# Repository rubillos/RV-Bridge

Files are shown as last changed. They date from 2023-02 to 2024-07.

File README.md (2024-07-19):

# RV-Bridge: HomeKit to RV-C Adapter

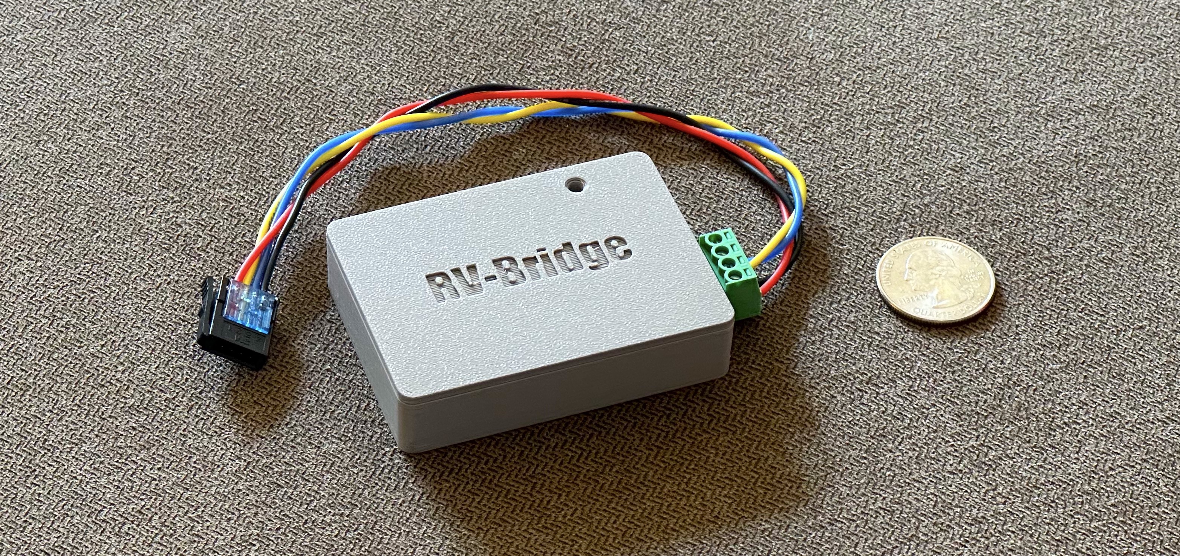
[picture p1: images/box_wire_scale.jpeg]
RV-Bridge


---

1. [Features](#features)
2. [Background](#background)
3. [Current Project State](#state)
4. [To-Do](#todo)
5. [Hardware](#hardware)
6. [Wiring](#wiring)
7. [Firmware Setup](#firmware)
8. [Finding Output Numbers](#outputs)
9. [Supported RVs](#rvs)
10. [3D Printing](#3dprint)
11. [Notes and Tips](#notes)
12. [Links](#links)

---
## Features

* Connects to the RV-C network in many modern RVs.
    * RV-C is a subset of CAN-Bus running at 250kbps.
* Uses an ESP32 with a CAN-Bus interface.
* Connects lights, fans, switches, and thermostats to HomeKit.
* Fits inside the RV wiring panel.
* Plugs into an unused CAN-Bus socket for power and data.
* STL files for a 3D printed case are included.

---
## Background

At the start of the pandemic we realized that international travel was going to be off the table for a significant duration. We decided it was time [to see more of the Western US](http://rickandrandy.com/map/index.html?RV) so we bought a class-A motorhome which we call ***The Penguin Express***. We've put [almost 30k miles on it so far](http://rickandrandy.com/?rvlife).

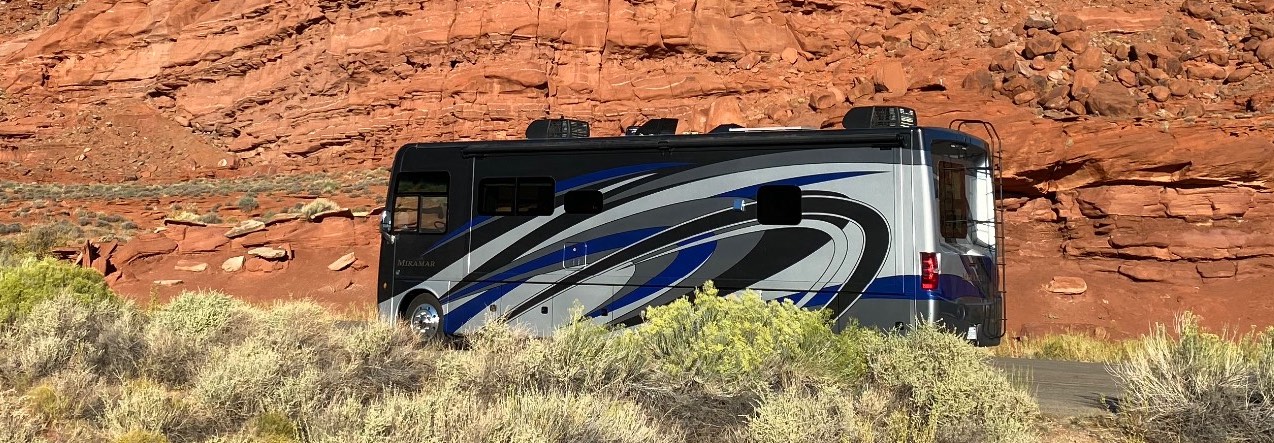
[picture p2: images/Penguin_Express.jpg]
Penguin Express


In addition to a bunch of 3D printed upgrades (we travel with a Prusa MK3S on board), I've done some arduino powered electronics work: a water valve for a reverse osmosis water filter with an LCD control panel, a GPS based clock for the bedroom that knows the exact timezone boundaries so it never needs to be set, and a GPS based altimeter and tire pressure monitor with a 7" color touchscreen for the dash.

The RV's lights, fans, and climate are all controlled through a [Firefly Integrations](https://fireflyint.com) [Vegatouch Spectrum](https://www.vegatouch.com) multiplex system. A 7" LCD panel is used to control everything, in addition to wireless keypads around the RV. There is also a bluetooth module that connects to an iOS app for controlling via an iPhone.

| | |
| --- | --- |
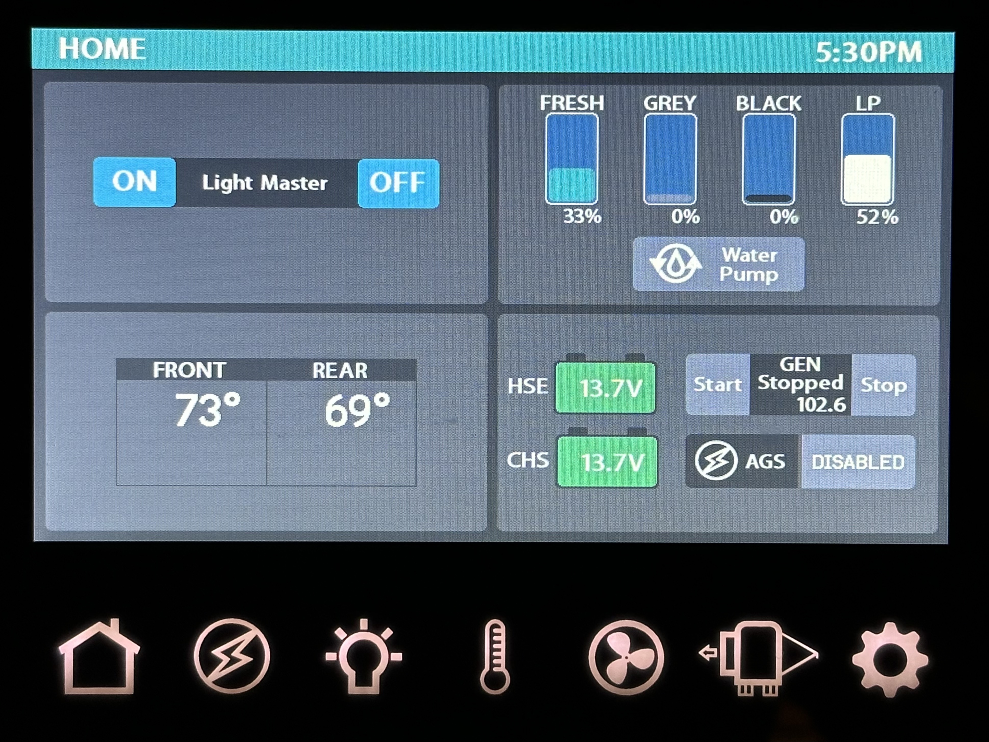
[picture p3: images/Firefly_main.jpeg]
Firefly Main
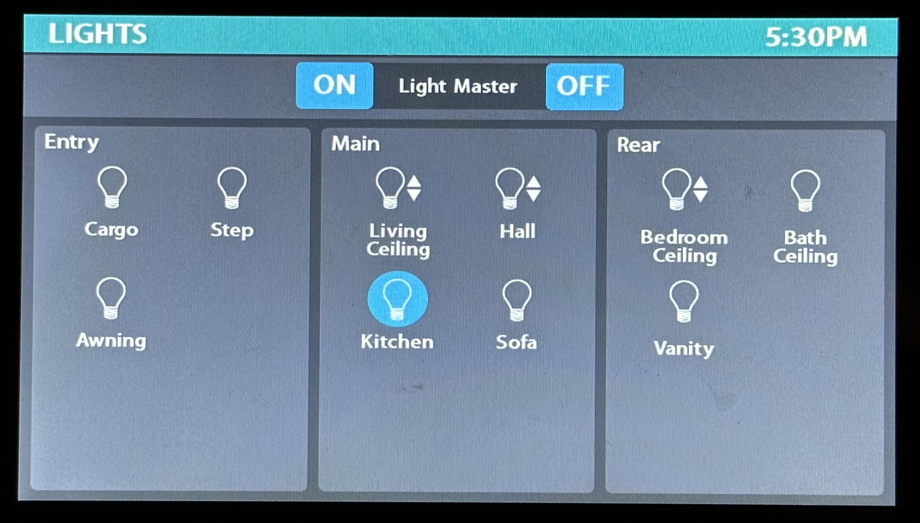
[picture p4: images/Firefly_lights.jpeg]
Firefly Lights
|  |  |
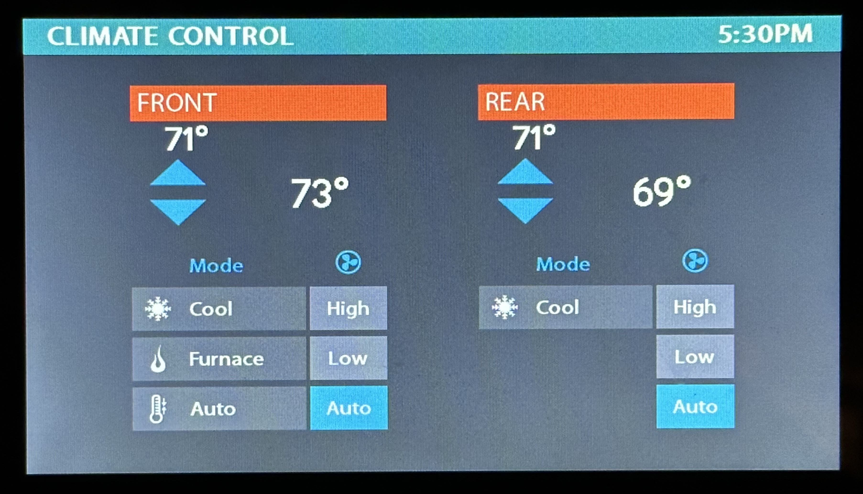
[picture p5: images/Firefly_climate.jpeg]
Firefly Climate
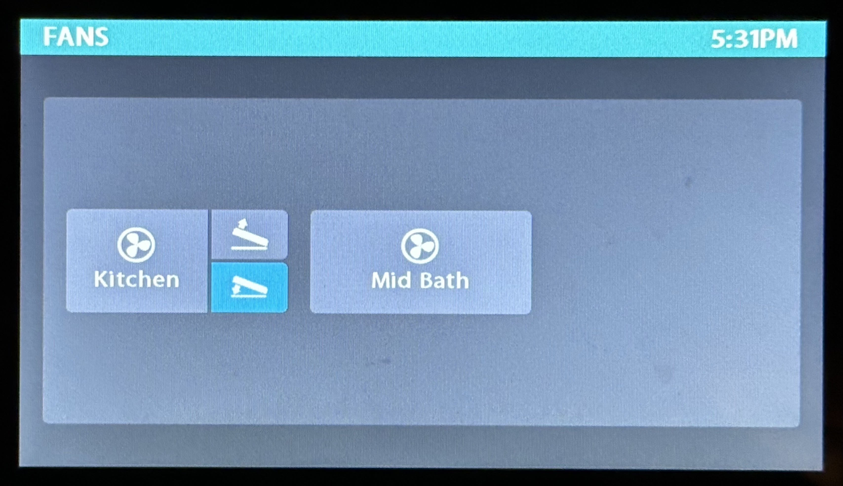
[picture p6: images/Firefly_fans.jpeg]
Firefly Fans
|  |  |

It's a great system and works really well for control of the RV devices, but the iOS app is a bit slow to load/connect and can only be used in proximity to the RV. Since we already have an Apple TV onboard driving our TVs which could double as a hub, I've always wondered if there was a way to control it all via HomeKit and the Home app.

Recently I came across some documentation for the bus protocol that's used by the Spectrum system, RV-C, a subset of CAN-Bus, as well as the open source project [CoachProxyOS](https://github.com/linuxkidd/coachproxy-os) that documents getting a Raspberry Pi set up to host a web page for controlling an RV's network using RV-C.

I also recently started playing with [HomeSpan](https://github.com/HomeSpan/HomeSpan), a library for implementing HomeKit accessories on an ESP32 microcontroller, for a HomeKit doorbell project.

RV-Bridge is the result of putting these pieces together.

---
## Current Project State

## v1.0.9 - In progress
* Added option to create two "Thermostats" which show the voltage of the chassis and house batteries as temperature * 10
* Added support for exterior awnings.

## v1.0.0
* Homespan pairing works, devices show up in the Home app.
* CAN-Bus packet receiving works.
* RV-C messages are routed correctly to the HomeKit tiles.
* The correct RV-C packets are being sent over the bus based on changes made in the Home app for lights, switches, and fans.
* The RV devices respond correctly.
* Lights, switches, and fans are complete.
* Temperature readings from thermostats are reflected in the Home app.
* Thermostat control is complete.

---
## To-Do

* Some RVs have AC units that can work as a heat pump; only the AC portion of these units is currently handled. (Ours only has a furnace so I don't currently have a way to implement this.)

---
## Hardware

Uses an ESP32 with a CAN-Bus interface, either as separate components, or more easily, this board I found from [skpang.co.uk](https://www.skpang.co.uk):

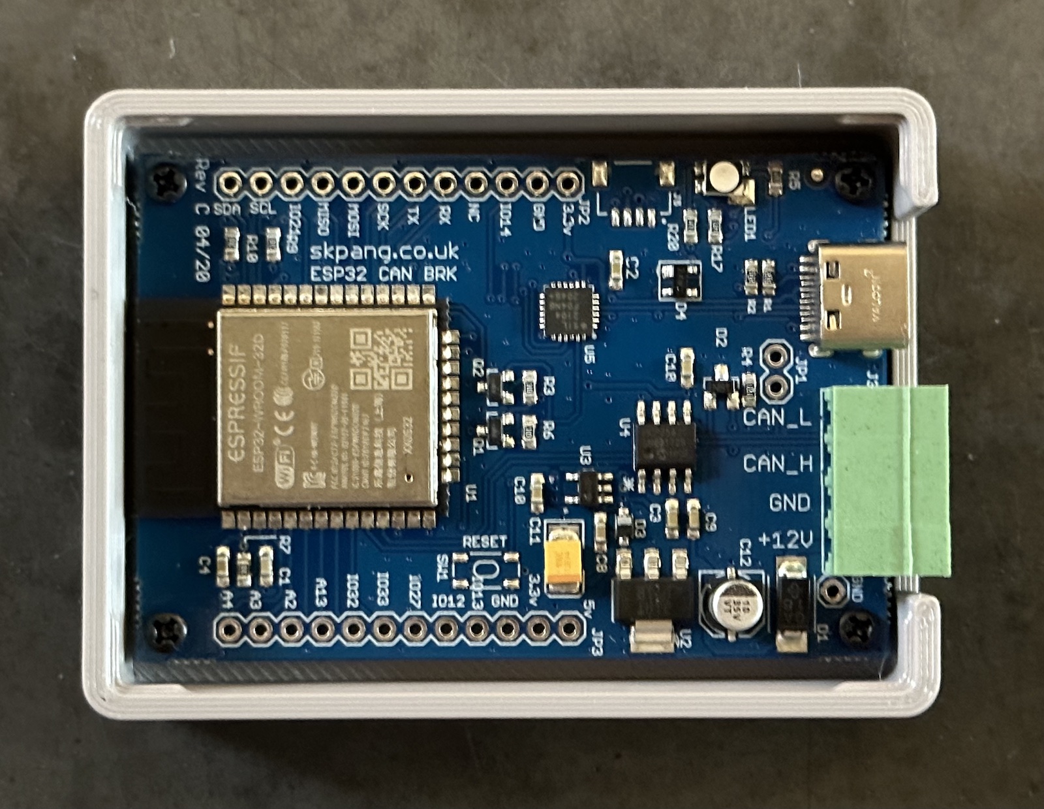
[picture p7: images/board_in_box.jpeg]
ESP32 Module


In the U.S. it's available on the CopperHillTech Website:<br>
[ESP32 with WiFi, Bluetooth Classic, BLE, CAN Bus Module](https://copperhilltech.com/esp32-wifi-bluetooth-classic-ble-can-bus-module/)

This board has everything needed, including a regulator for powering the device off of the 12V provided by the RV-C connector.

---
## Wiring

The connector used by the Firefly system is a ***3M 37104-A165-00E MB*** which can be sourced from [Digikey](https://www.digikey.com/en/products/detail/3m/37104-A165-00E%2520MB/1855697)

Insert four 24AWG wires into the Can-Bus connector (I used silicone covered wire as they are much more flexible) and compress to make the connections. Twist the data and power pairs together and screw them into the terminal block on the CAN-Bus interface on the ESP32.

The CAN-Bus connector plugs into one of the available sockets inside the system wiring panel.

|  |  |
| :---: | :---: |
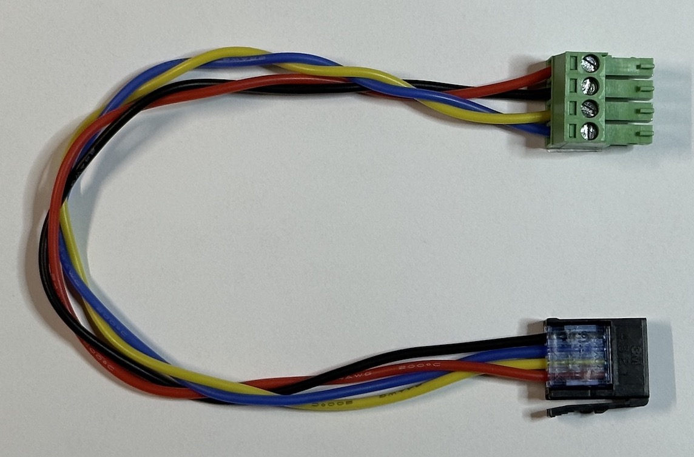
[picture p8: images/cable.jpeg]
Cable Wiring
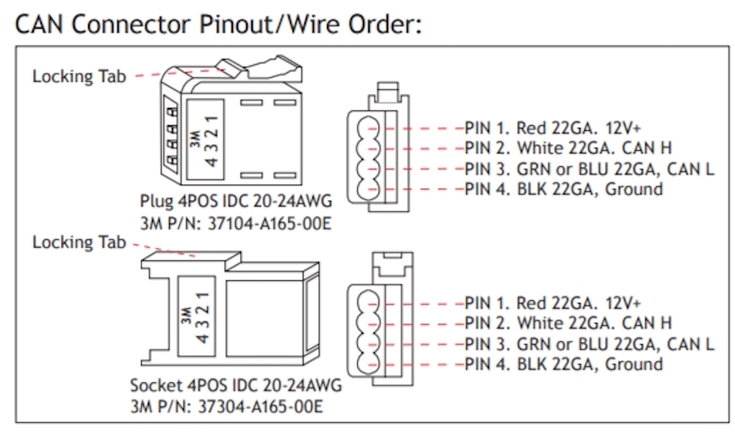
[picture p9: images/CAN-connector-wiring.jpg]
Can-Bus Connector Wiring
| <br> | |
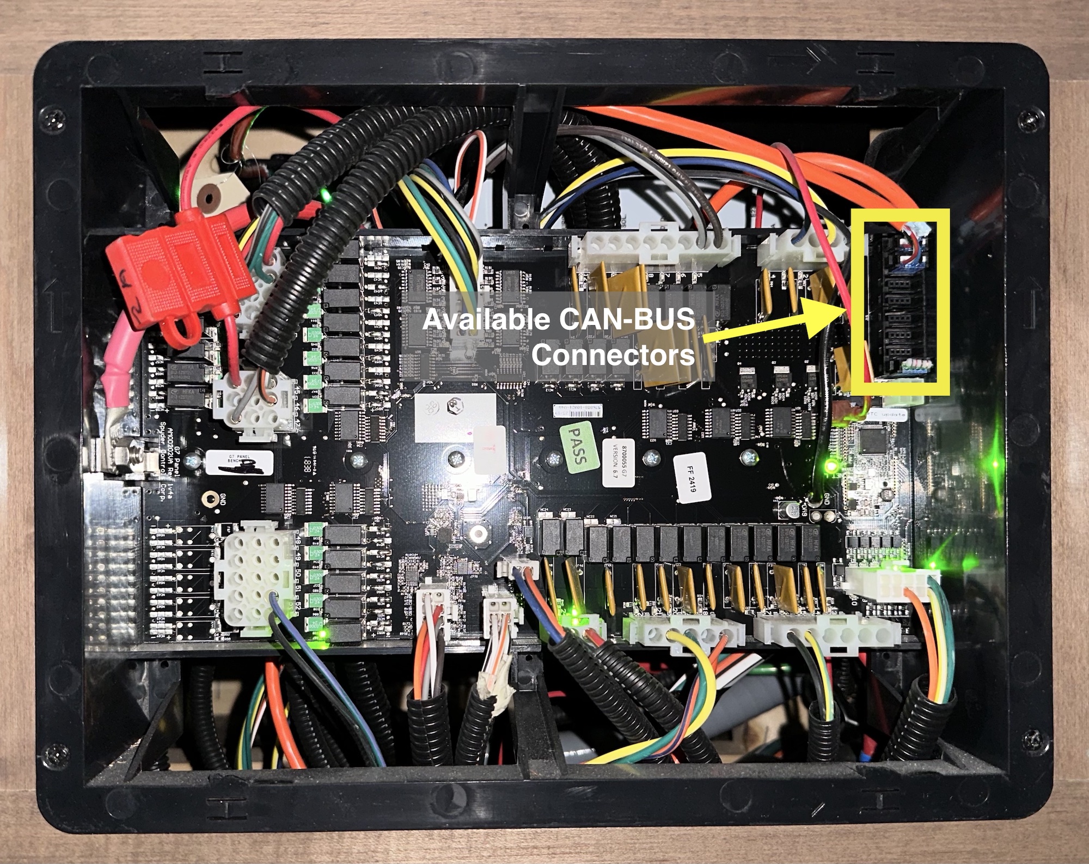
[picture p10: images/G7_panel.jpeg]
G7 Panel
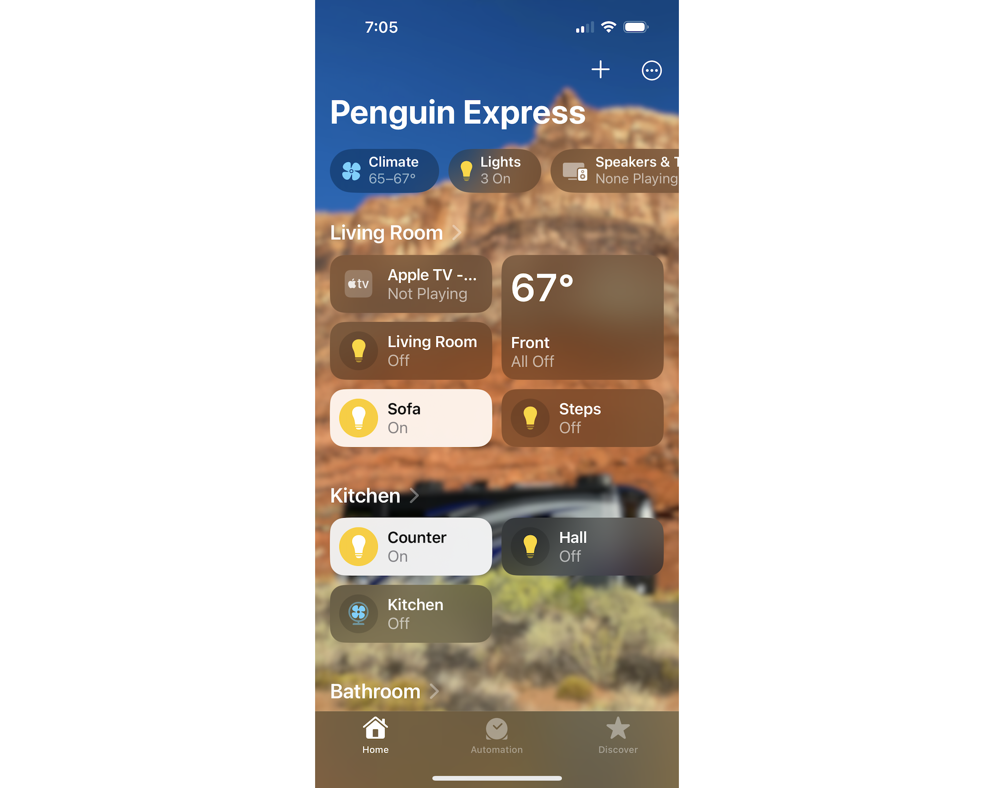
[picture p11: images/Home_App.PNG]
Home App
|  |  |

---
## Firmware Setup

- The project is set up for compilation with PlatformIO.
    * I use it via Microsoft's Visual Studio Code.
- Pretty sure you could also use the Arduino IDE. You'd need to install the following libraries:
    * elapsedMillis
    * miwagner/ESP32CAN
    * homespan/HomeSpan
- `config.h`
    * Duplicate `config-sample.h` to `config.h`. (Do not check this file into git, it will have your wifi passowrd in it)
    * Enter Wifi SSID and password for your RV network.
    * Include a definition file for your RV devices (see `Miramar_2020_3202.h` for an example).
        * Each switch has:
            * Output number.
            * Type: Lamp, DimmableLamp, or Switch.
            * Name.
        * Each fan has:
            * Output number for fan power.
            * Output number for up - optional, -1 if not used.
            * Output number for down - optional, -1 if not used.
            * Name.
        * Each thermostat has:
            * ID number, typically 0 based.
            * Output number for the A/C compressor.
            * Output number for low fan.
            * Output number for high fan.
            * Output number for furnace - optional, -1 if not present.
            * Name.
        * Each awning has:
            * Output number for extend.
            * Output number for retract.
            * Time (in ms) that the awning takes to get to the "unroll" portion.
            * Time (in ms) that the awning takes to "unroll" at the end. Set to 0 if not applicable.
            * Time (in ms) that the awning takes to get from the "roll" portion to fully retracted.
            * Time (in ms) that the awning takes to "roll" at the beginning. Set to 0 if not applicable.
            * Name.
        * See [Finding Output Numbers](#outputs) below for details on output numbers.
    * Uncomment `#define CREATE_BATTERIES` to create "Thermostats" for the house and chassis batteries.
        * The "thermostat" will show the current battery voltage times 10 as temperature.
            * Homekit does not currently have a way to display voltages, so this is my hack to be able to see this very useful information.
        * You will likely want to turn off "Include in Home Summaries" in the Status setting for these "thermostats".
        * When in screen "rearrange" mode you can tap on a thermostat and choose to show it in a smaller sized tile.
- Flashing
    * If you are using an ESP32 with a USB-C connector and flashing from a Mac, you may need to connect it via a USB hub due to some timing weirdness around resetting the ESP32 into boot mode. I use a USB-C to 4 port USB-A hub with a USB-A to USB-C cable.
- Startup
    * Connect to the ESP32 via the Serial Monitor.
    * You should see a bunch of startup logging.
    * Then a message about being connected to Wifi and not being paired.
    * HomeSpan provides a command line interface that you can access through the Serial Monitor. Type '?' to see the available comands.
- Pairing
    * Be on the same wifi network and in close proximity to the ESP32.
    * In the Home app choose "Add Accessory".
    * Point the camera at this image:
    <br><br>
    Pairing Code
    <br><br>
    * Tap on `RV-Bridge`.
    * Accept that this is an "unsupported" device.
    * Add the bridge and all of your accessories, choosing appropriate rooms and names for them.
    * Done!
- The status LED will flash based on what the bridge is doing:
    * 🟢 Green every 2 seconds as a heartbeat indicator.
    * 🔴 Red when CAN-Bus packets are sent.
    * 🔵 Blue when HomeKit messages are received.

---
## Finding Output Numbers

The whole multiplex system connects back to a panel with outputs for all of the lights and fans. Each of these outputs has a unique number which may be printed on the panel's cover, and should also be found on a Network Diagnostic screen on the main LCD control screen.

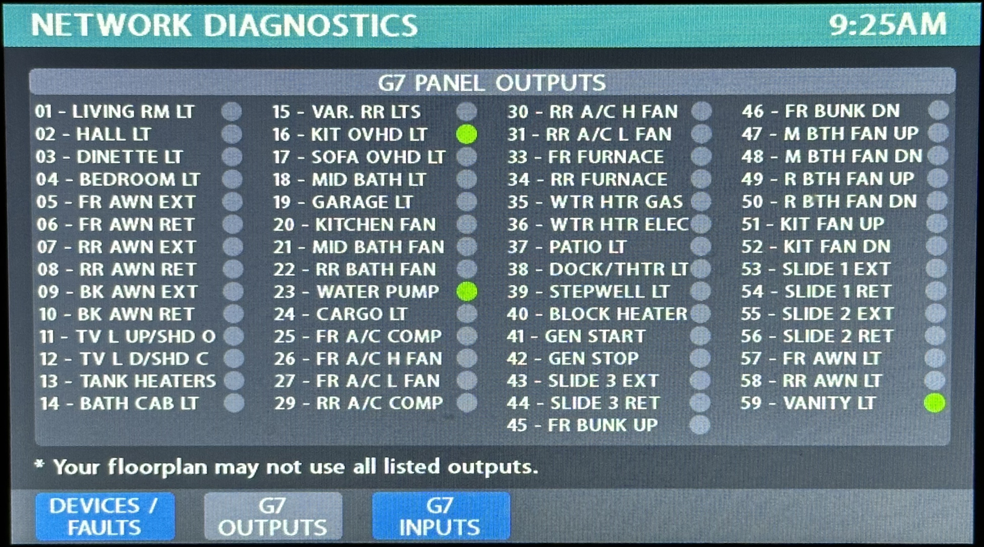
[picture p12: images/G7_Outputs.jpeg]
G7 Outputs


*** ***USE EXTREME CAUTION WHEN ENTERING OUTPUT NUMBERS. THERE ARE OUTPUTS FOR THE RV SLIDES AND THINGS LIKE MOVEABLE BUNKS. YOU DO NOT WANT TO MISTAKENLY PICK ONE OF THOSE OUTPUTS FOR A LIGHT OR FAN!*** ***

---
## Supported RV's

Currently the project includes definition files for these RVs in the `RV` folder:

[Miramar_2020_3202.h](/src/RV/Miramar_2020_3202.h) - 2020 Thor Miramar 32.2<br>
[Aria_2019_3901.h](/src/RV/Aria_2019_3901.h) - 2019 Thor Aria 39.1<br>
[Tiffin_2019_34PA.h](/src/RV/Tiffin_2019_34PA.h) - 2019 Tiffin Open Road 34PA<br>
[Jayco_2023_Terrain.h](/src/RV/Jayco_2023_Terrain.h) - 2023 Jayco Terrain 19Y

(Additional definition files are welcome!)

---
## 3D Printing

- A case will keep the microcontroller isolated from any exposed contacts inside the wiring panel.
- STL Files are in the `3D` folder:
    * [RV-Bridge_Box_Bottom.stl](/3D/RV-Bridge_Box_Bottom.stl)
    * [RV-Bridge_Box_Top.stl](/3D/RV-Bridge_Box_Top.stl)
- Slicer
    * I used Prusa Slicer 2.5.0
- Build Plate
    * A textured build plate give a nice surface finish for the top and bottom of the box.
- Filament
    * PETG - handles heat better than PLA and sticks to a textured build plate much better than PLA.
- Settings to adjust:
    * `Layer Height`: 0.3mm (faster printing)
    * `Extrusion Width`: 0.55mm (eliminates tiny infill strips in the walls).
    * `Perimeter Transitioning Threshold Angle`: 20 (keeps the lettering connected).
    * `Bridging Angle`: 180º (bridging in the layer above the lettering should be parallel to the baseline of the text.)

---
## Notes and Tips

- If the bridge seems to become unresponsive at some point, verify that the controlling device is on the RV's Wifi and not some other weak Wifi.
- If the bridge doesn't seem available for pairing, it may already think it's paired. Try using the H command via the cli in the serial monitor, then reflash the ESP32 and try again.
- If pairing fails, it seems that sometimes HomeKit gets fussy about a device changing it's properties too much and refuses to pair. You can change the MAC address of the wifi interface on the ESP32 by defining `OVERRIDE_MAC_ADDRESS` in `config.h` and re-flashing. Anecdotal evidence suggests that this can help.

---
## Links:

- [Apple's HomeKit Accessory Protocol Specification Release R2 (HAP-R2)](https://developer.apple.com/homekit/specification/)
    * For some reason this link appears to be broken on the Apple side at the moment... with _just a tiny bit_ of hunting on the internet you can find it 😉
- [RV-C Organization](http://www.rv-c.com)
- [RV-C Spec 2022-12-01](http://www.rv-c.com/sites/rv-c.com/files/RV-C%20Protocol%20FullLayer-12-01-22.pdf)
- [SK Pang Electronics](https://www.skpang.co.uk)
- [Schematic for the ESP32 CAN-Bus Board above](https://cdn.shopify.com/s/files/1/0563/2029/5107/files/ESP32_CAN_rev_B.pdf?v=1620032162)

---

Copyright © 2023-2024 [Randy Ubillos](http://rickandrandy.com)

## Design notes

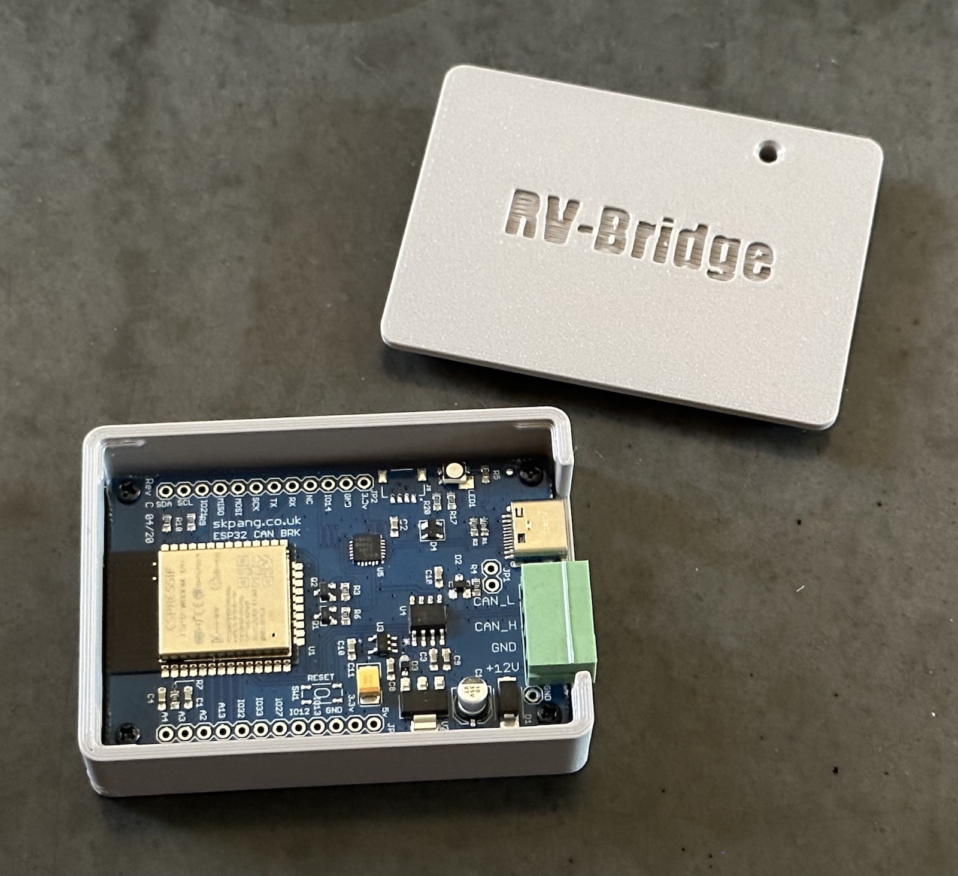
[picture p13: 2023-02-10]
images/open_box.jpeg

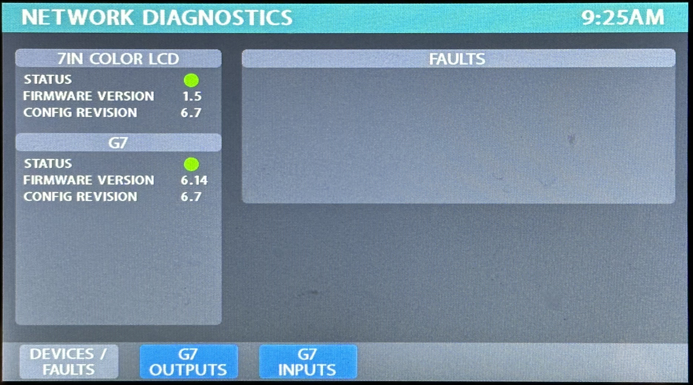
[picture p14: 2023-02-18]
images/G7_Devices.jpeg

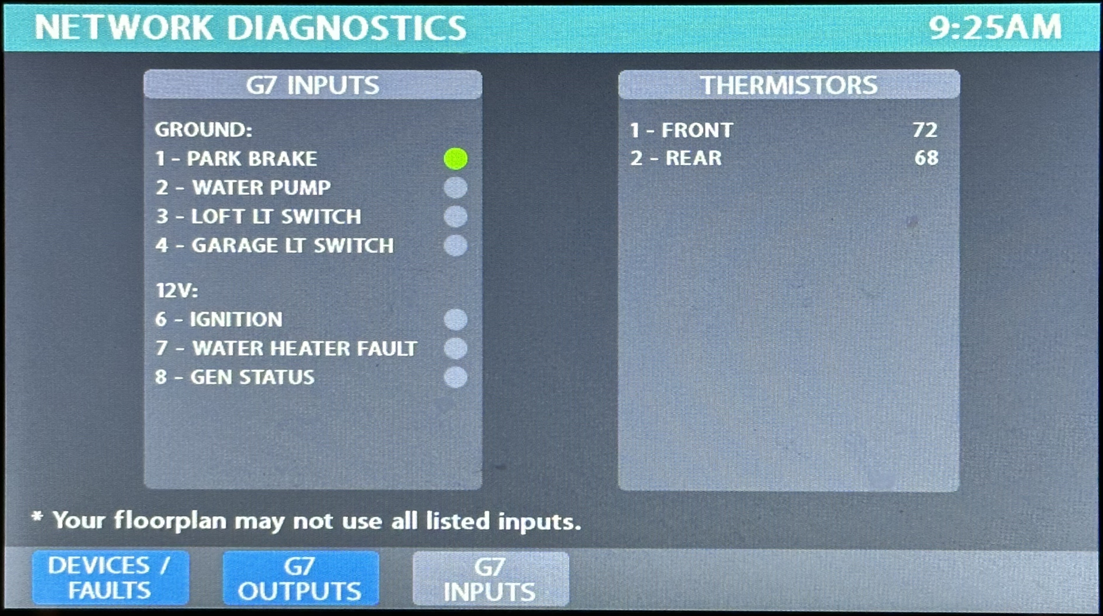
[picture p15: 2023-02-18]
images/G7_Inputs.jpeg

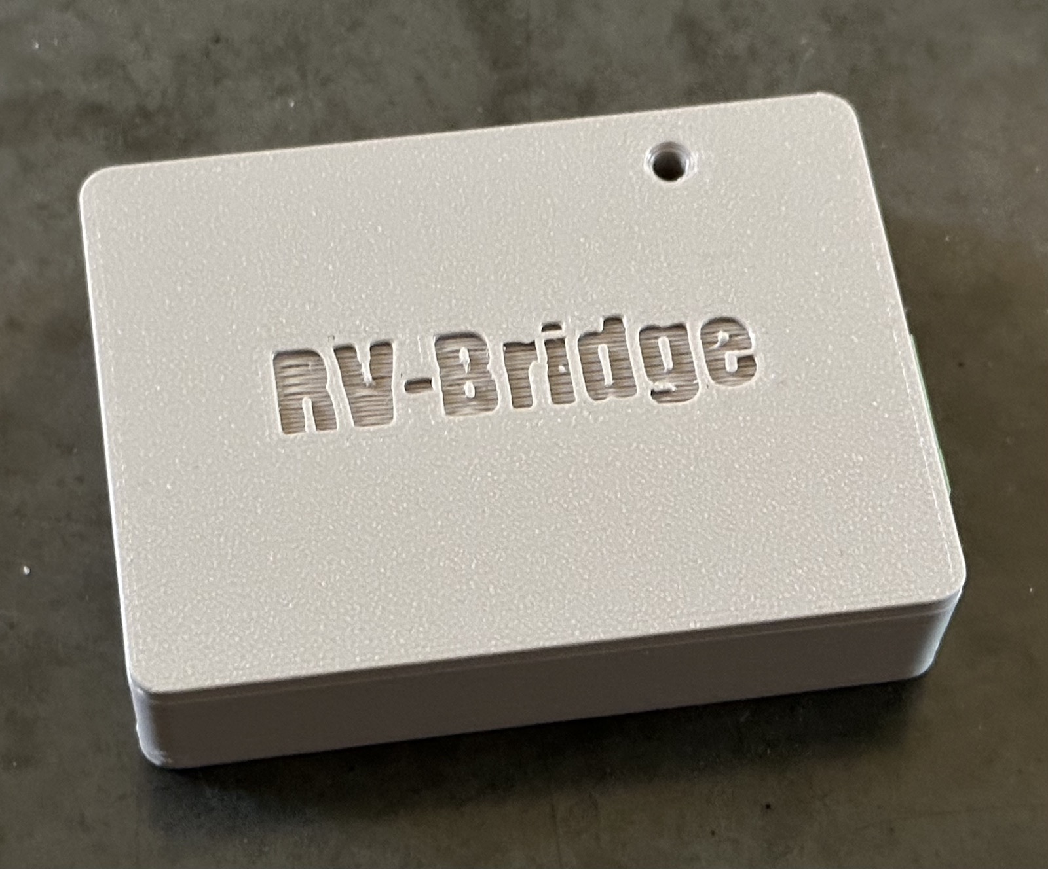
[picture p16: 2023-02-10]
images/box.jpeg

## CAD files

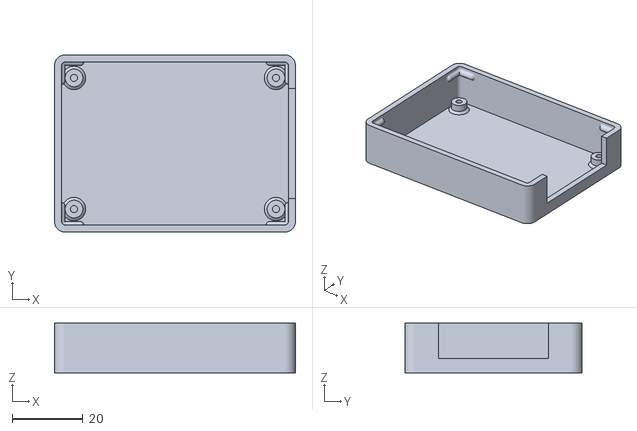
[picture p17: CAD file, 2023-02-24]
3D/RV-Bridge_Box_Bottom.stl
68.0 x 50.0 x 14.0

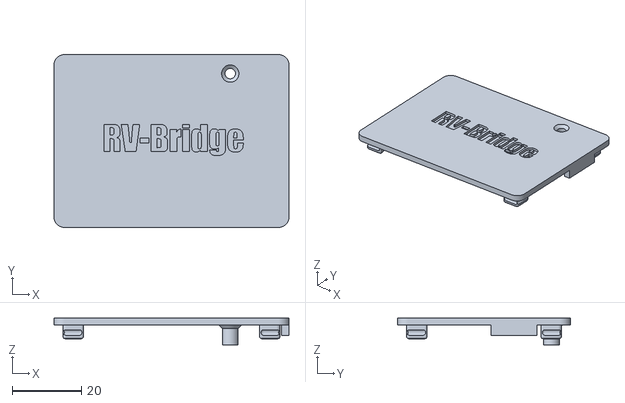
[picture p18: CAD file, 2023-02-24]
3D/RV-Bridge_Box_Top.stl
68.0 x 50.0 x 7.80

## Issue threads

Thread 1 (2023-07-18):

Can I use a Rpi and CAN board instead of the micro controller?

oilcan-productions, 2023-07-18:
I have a coachproxy setup from a previous project that I abandoned a year ago. Could the software be adapted to run on an RPi 4 with a CAN board attached>

rubillos, 2023-07-19:
That wouldn’t be easy… this project is codes using the HomeSpan library which is designed for the ESP32. I think you’d have an easier time using the coachproxy definition files for your Motorhome to define a setup file for this project.

oilcan-productions, 2023-07-27:
Thanks I got one of the ESP32 boards now.

Closed 2023-07-27.

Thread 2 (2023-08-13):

Feature Request: Awning Control and Heat Pump

kwe1009, 2023-08-13:
I have a 2019 Tiffin and your code works great with it but I would like to be able to control my awning and heat pump.  I'm not much of a programmer and all of my attempts to make this happen have been unsuccessful at best.

rubillos, 2023-08-14:
I'm planning to add support for awnings in a couple of months (we store our RV about an hour away so I really only get to work on this software when I'm traveling in it). Awnings are a bit tricky because the software has to estimate the position of the awning based on the amount of time since the button presses. I have some ideas on how to implement it and will be working on it on our next trip in October.

Did you create a configuration file for you Tiffin? If so I'd love to incorporate it into this project. Thanks!

kwe1009, 2023-08-14:
Thanks.  Attached is my Tiffin file which I am still working on.  I had a
CoachProxy but the CAN bus board just died so I'm trying your solution
which I really like better.  I don't have Apple products but I'm using the
Home KIt bridge with Home Assistant and it is working great.

Michael W.

On Mon, Aug 14, 2023 at 10:47 AM Randy Ubillos ***@***.***>
wrote:

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

rubillos, 2023-08-14:
I don't think GitHub has a way to add attachments to issues. (If you replied to the GitHub email any attachment would be ignored). Could you send the file to my email at randy@mac.com? Thanks!

rubillos, 2023-08-16:
Great, got the file, thanks!

Closed 2023-08-16.

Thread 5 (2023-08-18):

Enhancement: Support heat pump heating

rubillos, 2023-08-18:
Placeholder for planned future feature.

pbryan7, 2024-01-29:
I just got RV-Bridge working in my 2022 Entegra Vision XL 36A (I'll work on uploading a config file).   My unit has 2 A/C's, 2 Gas Furnaces, and the Heat Pump option on the Front A/C.  Through firefly it has 2 thermostat zones (front & rear).   The rear has A/C and Gas Furnace.   The Front has A/C, Heat Pump, & Gas Furnace.  Pretty close to max complexity on the HVAC.    I'm happy to help in any way I can to get the HeatPump working through RV-Bridge.

rubillos, 2024-01-29:
That's great! If you send me your config file I'll add it to the project.

As for the heat pump, it's hard for me to code that as we don't have on in our RV. Could you take pictures of the "G7 Panel Outputs" screen on your FireFly system in 4 states?

- Off
- A/C cooling
- Heatpump heating
- Furnace running

That would let me see what your system needs for the various modes.

Thanks,
Randy

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

pbryan7, 2024-01-30:
So I actually have a G12 not a G7, but all the output numbering seems to work the same.

Here's a pic of the overall outputs, next time I'm out at the RV I'll try to get pics of the different modes working, but it seems the heat pump is just another numbered output like the A/C Compressor or Furnace Enable  (See output #10)...

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

rubillos, 2024-01-30:
Good to know, that’s kind of what I was expecting.HomeKit doesn’t have any concept of a heating system with 2 different heaters. It could either be done with a separate switch that selects the furnace or heat pump, or a whole other “thermostat” for the furnace where the two thermostats turn each other off. Thoughts?RandyOn Jan 29, 2024, at 5:43 PM, pbryan7 ***@***.***> wrote:
So I actually have a G12 not a G7, but all the output numbering seems to work the same.
Here's a pic of the overall outputs, next time I'm out at the RV I'll try to get pics of the different modes working, but it seems the heat pump is just another numbered output like the A/C Compressor or Furnace Enable  (See output #10)...
20240126_194321.jpg (view on web)

—Reply to this email directly, view it on GitHub, or unsubscribe.You are receiving this because you were assigned.Message ID: ***@***.***>

pbryan7, 2024-01-30:
Ultimately I'm hoping to create some automatons around the thermostat, possibly connecting the RV-bridge to a Home Assistant instance...

Ideally, I'd be able to choose either Heat Pump, or Furnace, or both (I think it will work that way through the screen).  I don't have a strong preference on how that would be accessed...   Maybe it would make the most sense to have switches that would enable/disable the heating devices actuated by the main thermostat?

rubillos, 2024-01-30:
Hadn’t considered both at the same time… is that possible? I don’t see anything in the RV-C spec that would allow that. Would be great if you could confirm in the coach that that actually works.RandyOn Jan 29, 2024, at 7:04 PM, pbryan7 ***@***.***> wrote:
Ultimately I'm hoping to create some automatons around the thermostat, possibly connecting the RV-bridge to a Home Assistant instance...
Ideally, I'd be able to choose either Heat Pump, or Furnace, or both (I think it will work that way through the screen).  I don't have a strong preference on how that would be accessed...   Maybe it would make the most sense to have switches that would enable/disable the heating devices actuated by the main thermostat?

—Reply to this email directly, view it on GitHub, or unsubscribe.You are receiving this because you were assigned.Message ID: ***@***.***>

rubillos, 2024-01-30:
And just a note: you can create more automations with HomeKit than what the Home app allows. Something like the Eve app allows more complex automations to be created without needing Home Assistant.RandyOn Jan 29, 2024, at 7:04 PM, pbryan7 ***@***.***> wrote:
Ultimately I'm hoping to create some automatons around the thermostat, possibly connecting the RV-bridge to a Home Assistant instance...
Ideally, I'd be able to choose either Heat Pump, or Furnace, or both (I think it will work that way through the screen).  I don't have a strong preference on how that would be accessed...   Maybe it would make the most sense to have switches that would enable/disable the heating devices actuated by the main thermostat?

—Reply to this email directly, view it on GitHub, or unsubscribe.You are receiving this because you were assigned.Message ID: ***@***.***>

pbryan7, 2024-02-03:
OK, so I tested it today...   you can definitely have both the heat pump and furnace on at the same time.   Works both through the screen in the unit, see screenshots below, and through the phone app.

Heat Pump Only:
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

Heat Pump + Furnace:
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

rubillos, 2024-02-03:
Thanks, that's great info! I think I know how this is handled now. I'll get something coded up and we can see. (Note: I'm traveling for the next 2 months, so it will be a bit before I can get to this).

pbryan7, 2024-09-09:
> Thanks, that's great info! I think I know how this is handled now. I'll get something coded up and we can see. (Note: I'm traveling for the next 2 months, so it will be a bit before I can get to this).

Just checking in to see if there are any updates on this one...

pbryan7, 2025-05-15:
I was able to play with this a little this week...   After looking at the RV-C spec, and seeing that for a given thermostat instance the 'heat' mode is actually the heat pump (if available), and not the furnace, it gave me an idea that I could potentially make multiple thermostat entries in the config file.

The good news is that it seems to actually be working...    I'll have to play a bit more, but in a few tests today, I was able to choose to turn on & off the A/C, Heat Pump, & Furnace separately...

 In my case I have Front & Rear roof A/C (only the front has a Heat Pump), and I have front and rear propane furnaces.

I set up 4 thermostats like this:

const ThermostatDeviceRec thermostatList[] = {
    0, 9, 11, 12, 0, 10, "Front Roof",
    1, 13, 15, 16, -1, -1, "Rear Roof",
    0, 9, 11, 12, 2, 39, "Front Furnace",
    1, 13, 15, 16, 3, 2, "Rear Furnace"

Ideally there would be a way to define the furnace only thermostats, I wasn't sure what I should do with the A/C side of the furnace entries, so I just replicated the roof a/c instances & output numbers, but it seems to work fine.  You can see my output #'s in the photos above...   Notice I used the instance # of 0 for both the A/C & Heat items in the first thermostat, that is the key to accessing the heat pump.

Might be a little hacky, but so far seems to be working, at least in my unit (2022 Entegra Vision XL)...

shaferz, 2025-07-23:
Good stuff.  We are acquiring a new Brinkley that is coming with the firefly control system.  All 3 roof units have heat pumps, plus the propane furnace on top of that.  I've already got the ESP32 board, wiring connectors, etc.  Rig should be delivered in early October, so hoping by the end of October, I've got some time to really play around with this. 😎

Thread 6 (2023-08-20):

Add capability to configure Wi-Fi settings without rebuilding the code

oilcan-productions, 2023-08-20:
I have several Wi-Fi hotspots I use the adapter with. currently I modified a private build to scan for Wi-Fi and select the right access point  and password from a list rather than a single AP in the config file.

I think the functionality that if the configured wifi is not found the device comes up in AP mode and I can connect to a simple page to configure wifi there and write that to the NVRAM or the config file would be great.

oilcan-productions, 2023-08-20:
I am going to take a stab at this over the next 2 weeks or so and send a PR

rubillos, 2023-09-05:
Great! (I'd suggest just adding a #ifdef on said around setWifiCredentials so if said is not defined then you can just use the HomeSpan serial commands to set/change the wifi setup).

mkostersitz, 2023-09-26:
Thanks for the suggestion. I submitted https://github.com/rubillos/RV-Bridge/pull/8/ with the change

rubillos, 2023-09-28:
Added ability to not set wifi credentials by defining SKIP_WIFI_CREDENTIALS.

Closed 2023-09-28.

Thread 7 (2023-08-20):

When plugged into CAN bus and USB/Serial no output in Serial terminal

oilcan-productions, 2023-08-20:
Not sure what happened it used to work fine. Now when I plug it into the socket at the back of the Van and the laptop at the same time I am not getting Serial output.

oilcan-productions, 2023-08-20:
I plugged it in the wrong way round. Needs to be Serial first and CAN bus after :)

Closed 2023-08-20.

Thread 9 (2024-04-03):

Just received Cooperhill ESP32 Can

rlust, 2024-04-03:
Checking to see if you have any words of advice to give this a try. I have an 2022 Entergra Aspire and added my devices to the config file.

carpenike, 2024-08-13:
Following here too. 2021 Entegra Aspire.

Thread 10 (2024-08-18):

Suddenly stopped working

kwe1009, 2024-08-18:
I had to get a new ESP-CAN Bus and I can't get it to connect to homekit.  I can see the device on the network but when I scan the image nothing happens.  I'm also using Home Assistant and tried adding it using their homekit integration and no luck there either.  I can ping the device and it is on the same network as Home Assistant and the iPhone.  I have reflashed it countless times and even redownloaded 1.0.0 and started from scratch.

Also, the OVERRIDE_MAC_ADDRESS doesn't work

Any suggestions?  Thanks.

rubillos, 2024-08-18:
Have you tried rebooting your HomeKit hub? (I had an LED light I made using HomeSpan become unresponsive. I tried debugging it but took a break when nothing seemed to work. A couple of days later I noticed it was working again so it seemed like the issue may have been on the HomeKit side).

If you have a second iOS device that could be a HomeKit Hub you might try creating a second "Home", move an iOS device to it to be the hub for that "Home", then try adding the RV-Bridge to that home. I don't know what stale data there is that could cause a problem on the HomeKit side, but starting a whole new "Home" seems like it would start completely from scratch. Just a wild guess.

kwe1009, 2024-08-18:
Thanks for the quick response.  I tried all of that and no love.  I'll give
it a few more days to see if it works.

Michael W.

On Sun, Aug 18, 2024 at 11:05 AM Randy Ubillos ***@***.***>
wrote:

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

kwe1009, 2024-08-18:
Any ideas on why the change MAC address isn't working?  Thanks.

Michael W.

On Sun, Aug 18, 2024 at 11:05 AM Randy Ubillos ***@***.***>
wrote:

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

rubillos, 2024-08-18:
So the MAC address isn't actually changing? I thought you meant changing it wasn't helping...

Two thoughts. First, I found this when searching the web:
```
Attention: the bit 0 of the first byte of MAC address can not be 1. For example, the MAC address can set to be “1a:XX:XX:XX:XX:XX”, but can not be “15:XX:XX:XX:XX:XX”.
```
Second, looks like there's and alternate call for setting the MAC address:
```
WiFi.mode(WIFI_STA);
esp_wifi_set_mac(WIFI_IF_STA, New_MAC_Address);
```
(Haven't tried this one myself).

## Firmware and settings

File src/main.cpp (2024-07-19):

/*********************************************************************************
 *  MIT License
 *  
 *  Copyright (c) 2023 Randy Ubillos
 *  
 *  https://github.com/rubillos/RV-Bridge
 *  
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
 ********************************************************************************/
 
////////////////////////////////////////////////////////////////
//                                                            //
//    RV-Bridge: A HomeKit to RV-C interface for the ESP32    //
//                                                            //
////////////////////////////////////////////////////////////////

#include "Arduino.h"

#include "elapsedMillis.h"
#include "HomeSpan.h" 
#include "ESP32CAN.h"
#include "CAN_config.h"

#include "config.h"

//////////////////////////////////////////////

constexpr const char* versionString = "v1.0.0";

constexpr uint8_t indicatorPinR = 2;
constexpr uint8_t indicatorPinG = 15;
constexpr uint8_t indicatorPinB = 4;

constexpr gpio_num_t canTxPin = GPIO_NUM_25;
constexpr gpio_num_t canRxPin = GPIO_NUM_26;

constexpr uint16_t receiveQueueSize = 10;
constexpr uint16_t sendQueueSize = 8;

constexpr uint32_t sendPacketIntervalmS = 50;
constexpr uint32_t minSendPacketIntervalmS = 5;

constexpr uint32_t packetBlinkTime = 25;
constexpr uint32_t heatbeatRate = 3000;
constexpr uint32_t heartbeatBlinkTime = 10;

elapsedMillis lastPacketSendTime = 1000;
elapsedMillis lastPacketRecvTime = 1000;

CAN_device_t CAN_cfg;               	// CAN Config

//////////////////////////////////////////////

enum {
	packetPrintNo = 0,
	packetPrintYes,
	packetPrintIfUnknown,
	packetPrintIfKnown
};

void displayPacket(CAN_frame_t *packet, uint8_t printPacket);
uint8_t packetPrintMode = packetPrintNo;

//////////////////////////////////////////////
// RV-C dgn numbers

constexpr uint32_t DATE_TIME_STATUS = 0x1FFFF;
constexpr uint32_t DC_DIMMER_COMMAND_2 = 0x1FEDB;
constexpr uint32_t DC_DIMMER_STATUS_3 = 0x1FEDA;
constexpr uint32_t THERMOSTAT_AMBIENT_STATUS = 0x1FF9C;
constexpr uint32_t THERMOSTAT_STATUS_1 = 0x1FFE2;
constexpr uint32_t THERMOSTAT_COMMAND_1 = 0x1FEF9;

constexpr uint32_t AIR_CONDITIONER_STATUS = 0x1FFE0; // 1FFE1
constexpr uint32_t GENERIC_INDICATOR_COMMAND = 0x1FED9;
constexpr uint32_t GENERIC_CONFIGURATION_STATUS = 0x1FED8;
constexpr uint32_t DC_SOURCE_STATUS_1 = 0x1FFFD;
constexpr uint32_t TANK_STATUS = 0x1FFB7;
constexpr uint32_t GENERATOR_STATUS_1 = 0x1FFDC;

constexpr uint32_t FURNACE_STATUS = 0x1FFE4;
constexpr uint32_t FURNACE_COMMAND = 0x1FFE3;

constexpr uint32_t INVERTER_TEMPERATURE_STATUS = 0x1FEBD;	
constexpr uint32_t DC_LOAD_STATUS_2 = 0x1FED;
constexpr uint32_t ATS_AC_STATUS_4 = 0x1FF85;
constexpr uint32_t ATS_STATUS = 0x1FFAA;	
constexpr uint32_t ATS_AC_STATUS_3 = 0x1FFAB;
constexpr uint32_t ATS_AC_STATUS_1 = 0x1FFAD;
constexpr uint32_t DC_LOAD_COMMAND = 0x1FFBC;
constexpr uint32_t DC_LOAD_STATUS = 0x1FFBD;
constexpr uint32_t AC_LOAD_STATUS = 0x1FFBF;
constexpr uint32_t CHARGER_AC_STATUS_1 = 0x1FFCA;
constexpr uint32_t INVERTER_STATUS = 0x1FFD4;
constexpr uint32_t INVERTER_AC_STATUS_1 = 0x1FFD7;

constexpr uint32_t AWNING_STATUS = 0x1FEF3;
constexpr uint32_t AWNING_COMMAND = 0x1FEF2;
constexpr uint32_t AWNING_STATUS_2 = 0x1FDCD;

constexpr uint32_t BATTERY_STATUS = 0x1AAFD;

//////////////////////////////////////////////

typedef enum {
	DCDimmerCmdSetBrightness = 0,
	DCDimmerCmdOnDuration,
	DCDimmerCmdOnDelay,
	DCDimmerCmdOff,
	DCDimmerCmdStop,
	DCDimmerCmdToggle,
	DCDimmerCmdMemoryOff,
	DCDimmerCmdRampBrightness,
	DCDimmerCmdRampToggle,
	DCDimmerCmdRampUp,
	DCDimmerCmdRampDown,
	DCDimmerCmdRampUpDown,
	DCDimmerCmdLock,
	DCDimmerCmdUnlock,
	DCDimmerCmdFlash,
	DCDimmerCmdFlashMomentarily,

	DCDimmerCmdNA = 255
} DCDimmerCmd;

typedef enum {
	ACModeAuto = 0,
	ACModeManual,

	ACModeNA = 3
} ACMode;

typedef enum {
	ThermostatModeOff = 0,
	ThermostatModeCool,
	ThermostatModeHeat,
	ThermostatModeAuto,
	ThermostatModeFanOnly,
	ThermostatModeAuxHeat,
	ThermostatModeDehumidify,

	ThermostatModeNA = 7
} ThermostatMode;

typedef enum {
	FanModeAuto = 0,
	FanModeOn,

	FanModeNA = 3
} FanMode;

constexpr double TempC_NA = 1775.0;

constexpr uint8_t RVCPercentMax = 250;
constexpr uint8_t RVCBrightMax = 200;
constexpr uint8_t RVCFanMax = 200;

constexpr float HomeKitPercentMax = 100;

//////////////////////////////////////////////

constexpr float homeKitShadeOpenValue = 100.0;
constexpr float homeKitShadeClosedValue = 0.0;

constexpr float homeKitAwningRetractedValue = homeKitShadeOpenValue;
constexpr float homeKitAwningExtendedValue = homeKitShadeClosedValue;

constexpr uint8_t homeKitPositionStateClosing = 0;
constexpr uint8_t homeKitPositionStateOpening = 1;

constexpr uint8_t homeKitPositionStateExtending = homeKitPositionStateClosing;
constexpr uint8_t homeKitPositionStateRetracting = homeKitPositionStateOpening;
constexpr uint8_t homeKitPositionStateStopped = 2;

constexpr float awningRollPortion = 5.0;
constexpr uint32_t awningOutputTimeMS = 500;
constexpr uint32_t awningUpdateHoldTimeMS = 500;

constexpr uint8_t homeKitTemperatureDisplayCelsius = 0;
constexpr uint8_t homeKitTemperatureDisplayFahrenheit = 1;

constexpr uint32_t updateTimeMS = 500;

typedef uint16_t AwningState;
constexpr uint16_t awningStateExtending = 1 << 3;
constexpr uint16_t awningStateRetracting = 1 << 4;
constexpr uint16_t awningStateMoving = awningStateExtending | awningStateRetracting;

constexpr uint16_t awningStateUserAction = 1 < 6;
constexpr uint16_t awningStateHomeKitAction = 1 << 7;

//////////////////////////////////////////////

uint64_t millis64() {
	volatile static uint32_t low32 = 0, high32 = 0;
	uint32_t new_low32 = millis();

	if (new_low32 < low32)
		high32++;

	low32 = new_low32;

	return (uint64_t) high32 << 32 | low32;
}

//////////////////////////////////////////////

uint32_t getMsgBits(uint32_t msg, int8_t startBit, int8_t numBits) {
	int8_t shift = startBit - numBits + 1;
	uint32_t mask = 0xFFFFFFFF >> (32 - numBits);

	return (msg >> shift) & mask;
}

uint32_t makeMsg(uint32_t dgn, uint8_t sourceID=0, uint8_t priority=6) {
	if (sourceID == 0) {
		sourceID = sourceAddress;
	}

	return (priority<<26) | (dgn << 8) | sourceID;	
}

//////////////////////////////////////////////

constexpr double tempCOffset = -273.0;
constexpr double tempCScale = 0.03125;
constexpr double tempCScaleInv = 1.0 / tempCScale;
constexpr double tempCRoundingOffset = -0.25;

double convToTempC(uint16_t value) {
	return tempCOffset + value * tempCScale + tempCRoundingOffset;
}

uint16_t convFromTempC(double tempC) {
	return (tempC - tempCOffset + 0.5) / tempCScale;
}

//////////////////////////////////////////////

inline float degCfromDegF(float degF) {
	return degF / 1.8;
}

inline float tempCfromTempF(float tempF) {
	return degCfromDegF(tempF - 32.0);
}

//////////////////////////////////////////////

CAN_frame_t packetQueue[sendQueueSize];
bool packetShortGap[sendQueueSize];
uint16_t packetQueueHead = 0;
uint16_t packetQueueTail = 0;
bool doCANWrite = true;

void processPacketQueue() {
	if (packetQueueHead != packetQueueTail) {
		uint16_t nextIndex = (packetQueueTail + 1) % sendQueueSize;
		uint32_t interval = (packetShortGap[nextIndex]) ? minSendPacketIntervalmS : sendPacketIntervalmS;

		if (lastPacketSendTime >= interval) {
			if (doCANWrite) {
				// printf("%u: CAN-Bus Send Packet\n", (uint32_t)millis());
				ESP32Can.CANWriteFrame(&packetQueue[nextIndex]);
			}
			else {
				printf("%u: ***SIMULATE*** CAN-Bus Send Packet\n", (uint32_t)millis());
			}
			packetQueueTail = nextIndex;
			lastPacketSendTime = 0;
		}
	}
}

void queuePacket(CAN_frame_t *packet, bool shortGap=false) {
	uint16_t nextIndex = (packetQueueHead + 1) % sendQueueSize;

	while (nextIndex == packetQueueTail) {	// wait if queue is full
		processPacketQueue();
	}

	packetQueueHead = nextIndex;
	packetQueue[packetQueueHead] = *packet;
	packetShortGap[packetQueueHead] = shortGap;
}

void initPacket(CAN_frame_t* packet, uint8_t index, uint32_t msgID) {
	packet->FIR.B.DLC = 8;
	packet->FIR.B.RTR = CAN_no_RTR;
	packet->FIR.B.FF = CAN_frame_ext;
	packet->MsgID = makeMsg(msgID);
	packet->data.u8[0] = index;
	for (auto i=1; i<8; i++) {
		packet->data.u8[i] = 0xFF;
	}
}

//////////////////////////////////////////////

void sendDCDimmerCmd(uint8_t index, uint8_t brightness, uint8_t cmd, uint8_t duration=0xFF) {
	CAN_frame_t packet;
	initPacket(&packet, index, DC_DIMMER_COMMAND_2);
	uint8_t* d = packet.data.u8;

	d[2] = min(brightness, RVCBrightMax);
	d[3] = cmd;
	d[4] = duration;
	d[5] = 0;				// no interlock

	queuePacket(&packet);

	// printf("%u: Queueing Dimmer packet: #%d, bright=%d, cmd=%d, dur=%d\n", (uint32_t)millis(), index, brightness, cmd, duration);
	// displayPacket(&packet, packetPrintYes);
	// printf("%u: ** Packet queued.\n", (uint32_t)millis());
}

void sendOnOff(uint8_t index, bool on, uint8_t brightness=RVCBrightMax) {
	printf("%u: sendOnOff: #%d to %d\n", (uint32_t)millis(), index, on);
	sendDCDimmerCmd(index, brightness, (on) ? DCDimmerCmdOnDuration : DCDimmerCmdOff);
	// sendDCDimmerCmd(index, brightness, DCDimmerCmdToggle);
}

void sendLampLevel(uint8_t index, uint8_t brightness) {
	if (brightness == 0) {
		sendOnOff(index, false);
	}
	else {
		printf("%u: sendLampLevel: #%d to %d\n", (uint32_t)millis(), index, brightness);
		sendDCDimmerCmd(index, brightness, DCDimmerCmdSetBrightness, 0);
	}
}

void sendThermostatCommand(uint8_t index, ThermostatMode mode, FanMode fanMode, uint8_t fanSpeed, double tempC) {
	CAN_frame_t packet;
	initPacket(&packet, index, THERMOSTAT_COMMAND_1);
	uint8_t* d = packet.data.u8;

	d[1] = mode | (fanMode << 4);
	d[2] = fanSpeed;

	uint16_t tempVal = convFromTempC(tempC);
	d[4] = d[6] = tempVal >> 8;
	d[3] = d[5] = tempVal & 0xFF;

	queuePacket(&packet);

	// printf("%u: Queueing Thermostat packet: #%d, mode=%d, fanMode=%d, temp=%0.1fºC\n", (uint32_t)millis(), index, mode, fanMode, tempC);
	// displayPacket(&packet, packetPrintYes);
	// printf("%u: ** Packet queued.\n", (uint32_t)millis());
}

//////////////////////////////////////////////

const char* switchTypes[3] = { "43", "43", "49" };
const char* switchHapNames[3] = { "LightBulb", "LightBulb", "Switch" };

struct RVSwitch : SpanService {
	SpanCharacteristic *_on;
	SpanCharacteristic *_brightness = NULL;
	int16_t _index;

	RVSwitch(SwitchDeviceRec *device) : SpanService( switchTypes[device->type], switchHapNames[device->type] ) {
		_index = device->index;

		REQ(On);
		OPT(Name);

		if (device->type == Lamp || device->type == DimmableLamp) {
			OPT(Brightness);
			OPT(Hue);
			OPT(Saturation);
			OPT(ColorTemperature);
		}

		_on = new Characteristic::On();

		if (device->type == DimmableLamp) {
			_brightness = new Characteristic::Brightness(HomeKitPercentMax);
			_brightness->setRange(0, HomeKitPercentMax, 5);
		}
	}
	
	boolean update() {
		if (_on->updated() || (_brightness && _brightness->updated())) {
			if (_brightness) {
				uint16_t newLevel = _on->getNewVal() * _brightness->getNewVal() * RVCBrightMax / HomeKitPercentMax;
				sendLampLevel(_index, newLevel);
			}
			else {
				sendOnOff(_index, _on->getNewVal());
			}
		}
		return(true);  
	}

	void setLevel(uint8_t index, uint8_t dcDimmerLevel) {
		bool on = dcDimmerLevel > 0;
		uint16_t level = dcDimmerLevel * HomeKitPercentMax / RVCBrightMax;

		if (index == _index && on != _on->getVal()) {
			printf("%u: Switch #%d: on = %d\n", (uint32_t)millis(), _index, on);
			_on->setVal(on);
			lastPacketRecvTime = 0;
		}
		if (_brightness && index == _index && on && level != _brightness->getVal()) {
			printf("%u: Switch #%d: level = %d\n", (uint32_t)millis(), _index, level);
			_brightness->setVal(level);
			lastPacketRecvTime = 0;
		}
	}
};

struct RVRoofFan : Service::Fan {
	SpanCharacteristic *_active;
	int16_t _index;
	int16_t _upIndex;
	int16_t _downIndex;

	bool _fanPower = false;
	bool _lidUp = false;

	RVRoofFan(FanDeviceRec *device) : Service::Fan() {
		_index = device->index;
		_upIndex = device->upIndex;
		_downIndex = device->downIndex;
		_active = new Characteristic::Active();
	}
	
	boolean update() {
		if (_active->updated()) {
			bool newValue = _active->getNewVal();
			sendOnOff(_index, newValue);
			if (_upIndex != -1 && _downIndex!=-1) {
				if (newValue) {
					sendOnOff(_downIndex, false);
					sendOnOff(_upIndex, true);
				}
				else {
					sendOnOff(_upIndex, false);
					sendOnOff(_downIndex, true);
				}
				_lidUp = newValue;
			}
			_fanPower = newValue;
		}

		return(true);  
	}
	
	void setLevel(uint8_t index, uint8_t level) {
		bool on = level > 0;
		bool changed = false;

		if (index == _index) {
			_fanPower = on;
			changed = true;
			lastPacketRecvTime = 0;
		}
		else if (index == _upIndex && on) {
			_lidUp = true;
			changed = true;
			lastPacketRecvTime = 0;
		}
		else if (index == _downIndex && on) {
			_lidUp = false;
			changed = true;
			lastPacketRecvTime = 0;
		}

		if (changed) {
			bool newState = _fanPower && (_upIndex==-1 || _lidUp);

			if (newState != _active->getVal()) {
				printf("%u: Fan #%d: active = %d\n", (uint32_t)millis(), _index, newState);
				_active->setVal(newState);
			}
		}
	}
};

// HomeKit thermostat values
enum {
	currentFanStateInactive = 0,
	currentFanStateIdle,
	currentFanStateBlowing,

	targetFanStateManual = 0,
	targetFanStateAuto,

	heatingCoolingStateOff = 0,
	heatingCoolingStateHeat,
	heatingCoolingStateCool
};

struct RVHVACFan : Service::Fan {
	SpanCharacteristic *_active;
	SpanCharacteristic *_currentState;
	SpanCharacteristic *_targetState;
	SpanCharacteristic *_speed;
	
	std::function<bool()> _updateFunction;

	int16_t _index;
	int16_t _fanHIndex;
	int16_t _fanLIndex;
	bool _fanHRunning = false;
	bool _fanLRunning = false;

	RVHVACFan(ThermostatDeviceRec *device, std::function<bool()> updateFunction) : Service::Fan() {
		_active = new Characteristic::Active(false);
		_speed = new Characteristic::RotationSpeed(0);
		_speed->setRange(0, HomeKitPercentMax, HomeKitPercentMax/2);
		_currentState = new Characteristic::CurrentFanState(currentFanStateIdle);
		_targetState = new Characteristic::TargetFanState(targetFanStateAuto);
	
		_index = device->coolingInstance;
		_fanHIndex = device->fanHIndex;
		_fanLIndex = device->fanLIndex;
		_updateFunction = updateFunction;
	}
	
	boolean update() {
		bool changed = false;

		if (_active->updated()) {
			printf("%u: RVHVACFan #%d - Active: %d\n", (uint32_t)millis(), _index, _active->getNewVal());
			changed = true;
		}
		if (_speed->updated()) {
			printf("%u: RVHVACFan #%d - Speed: %d\n", (uint32_t)millis(), _index, _speed->getNewVal());
			changed = true;
		}
		if (_targetState->updated()) {
			printf("%u: RVHVACFan #%d - Target State: %d\n", (uint32_t)millis(), _index, _targetState->getNewVal());
		}
		if (changed) {
			_updateFunction();
		}
		return(true);  
	}

	void setModeSpeed(FanMode fanMode, uint8_t speed) {
		bool newActive = fanMode == FanModeOn;
		speed = speed * HomeKitPercentMax / RVCPercentMax;

		if (newActive != _active->getVal()) {
			printf("%u: RVHVACFan #%d - setActive: %d\n", (uint32_t)millis(), _index, newActive);
			_active->setVal(newActive);
		}
		if (speed != _speed->getVal()) {
			printf("%u: RVHVACFan #%d - setSpeed: %d\n", (uint32_t)millis(), _index, speed);
			_speed->setVal(speed);
		}
	}

	void getModeSpeed(FanMode* fanMode, uint8_t *speed) {
		if (_active->getNewVal()) {
			*fanMode = FanModeOn;
			*speed = _speed->getNewVal() * RVCFanMax / HomeKitPercentMax;
		}
		else {
			*fanMode = FanModeAuto;
			*speed = 0;
		}
	}

	void setLevel(uint8_t index, uint8_t level) {
		bool on = level > 0;
		bool changed = false;

		if (index == _fanHIndex && on != _fanHRunning) {
			_fanHRunning = on;
			changed = true;
			lastPacketRecvTime = 0;
		}
		else if (index == _fanLIndex && on != _fanLRunning) {
			_fanLRunning = on;
			changed = true;
			lastPacketRecvTime = 0;
		}

		if (changed) {
			uint8_t newState = (_fanHRunning || _fanLRunning) ? currentFanStateBlowing : currentFanStateIdle;

			if (newState != _currentState->getVal()) {
				printf("%u: HVACFan #%d: currentState = %d\n", (uint32_t)millis(), _index, newState);
				_currentState->setVal(newState);
			}
		}
	}
};
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
void loop() {
	static elapsedMillis heartbeatTime;

	bool sendIndicator = lastPacketSendTime < packetBlinkTime;
	bool recvIndicator = lastPacketRecvTime < packetBlinkTime;
    
	if (sendIndicator || recvIndicator) {
		heartbeatTime = heartbeatBlinkTime;		// adjust next heartbeat time to avoid overlap with send/recv indicators
	}

	bool hearbeatIndicator = (heartbeatTime % heatbeatRate) < heartbeatBlinkTime;

	if (!wifiConnected) {
		hearbeatIndicator = (heartbeatTime % (heatbeatRate/4)) > heartbeatBlinkTime*5;
	}

	digitalWrite(indicatorPinG, !hearbeatIndicator);
	digitalWrite(indicatorPinR, !sendIndicator);
	digitalWrite(indicatorPinB, !recvIndicator);

	homeSpan.poll();

	// HomeSpan does not call the wifi callback after the first connection
	// We do that manually here
	if (hadWifiConnection && !wifiConnected) {
		static uint64_t nextWifiCheck = 0;
		uint64_t time = millis64();

		if (time >= nextWifiCheck) {
			if (WiFi.status()==WL_CONNECTED) {
				wifiReady();
			}

			nextWifiCheck = time + 500;
		}
	}

	CAN_frame_t packet;

	if (xQueueReceive(CAN_cfg.rx_queue, &packet, 0) == pdTRUE) {
		if (packetPrintMode != packetPrintNo) {
			displayPacket(&packet, packetPrintMode);
		}
		debugPacket(&packet);
		processPacket(&packet);
	}

	processPacketQueue();
}

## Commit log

2023-02-06 Connector wiring diagram
2023-02-10 Updates to current state or project
2023-02-10 Updated blinking. Changed Thermostat to have switch for fan override.
2023-02-10 Added STL files
    [RV-Bridge_Box_Bottom.stl, RV-Bridge_Box_Top.stl]
2023-02-10 Added send queue. Enforce minimum send packet gap. Send thermostat commands. Fan override switch now triggers packet send. Added setThermostat cli command.
2023-02-13 Changed fan override to lightbulb.
2023-02-15 Thermostat numbers are 0-based. Bathrrom fan does not have up/down outputs.
2023-02-15 Up/Down fan outputs may be unused.
2023-02-17 Send real RV-C packets. Set interlock field of dimmerCmd to 0 to prevent interlock issues. Added code to only change characteristic values during loop method. RV-C percent max is 250, not 200. Added 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
    [main.cpp]
2023-02-18 Removed delaying setting characteristic values into loop method, doesn't seem to make a difference. Limit RVC lamp brightness to 200.
    [main.cpp]
2023-02-18 Added cli command to disable CAN-Bus writing for debugging. Removed 'true' parameter for setVal calls, it's the default.
2023-02-19 Added device definitions for Aria 3901
2023-02-20 Removed watchdog timer code (for now).
2023-02-21 Moved 3D files to their own folder.
    [RV-Bridge_Box_Bottom.stl, RV-Bridge_Box_Top.stl]
2023-02-22 Switched some member from int8 to int16 to better handle -1 and 0-255.
2023-02-22 Added table of contents. Improved description of device records.
2023-02-23 Added timestamp at the front of all print statements.
2023-02-24 Updated 3D file for box top and bottom. Parets snap together better. Centers of letters are larger and should print better.
    [RV-Bridge_Box_Bottom.stl, RV-Bridge_Box_Top.stl]
2023-02-24 Fixed a couple of logic errors. Could have gotten HomeKit state out of sync temporarily.
    [main.cpp]
2023-03-01 Added furnaceInstance. Renamed a couple of furnace field names.
2023-03-01 Updated version to 1.0.0 Added note about heat pumps.
2023-03-09 Fixed rounding errors going to/from ºC to RV-C temps
    [main.cpp]
2023-08-17 Clarify duplicating config-sample.h rather than renaming it.
2023-09-28 Update to latest HomeSpan library. Add patch script to fix warning in ESP32CAN library.
2023-09-28 Added SKIP_WIFI_CREDENTIALS define. Initial changes for supporting awnings.
    [main.cpp]
2024-02-03 Adjusted temperature step from 0.5 to 1.0/1.8. Added #define for creating two fake 'thermostats' to show current house/chassis battery voltage (*10). Beginnings of code for controlling exterior awnin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
    [main.cpp]
2024-07-18 Reworked the awning logic.
    [main.cpp]
2024-07-19 More awning work: Reversing while in motion works correctly now. Increased output on time from 300ms to 500ms.
    [main.cpp]
